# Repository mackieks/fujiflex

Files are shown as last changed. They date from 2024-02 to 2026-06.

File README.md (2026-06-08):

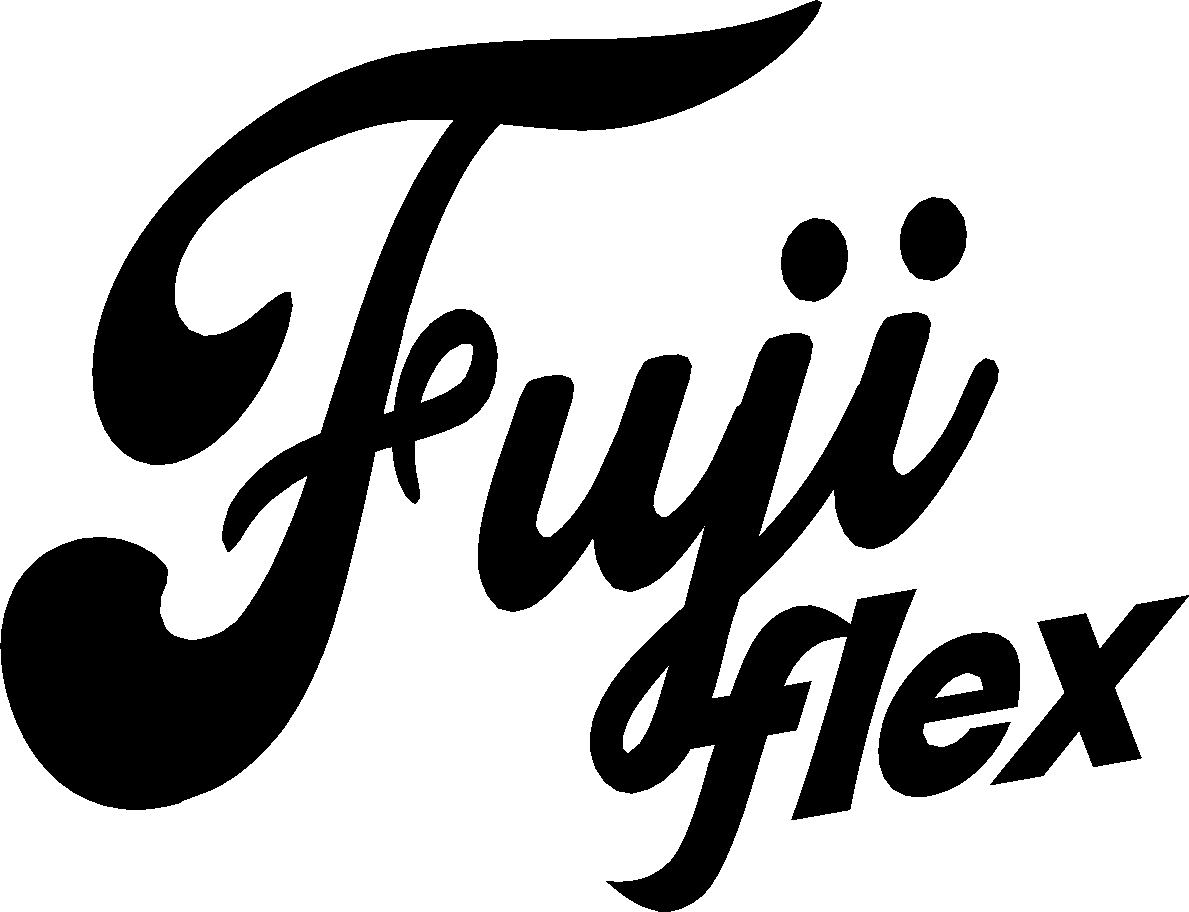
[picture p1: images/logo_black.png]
<picture> <source media="(prefers-color-scheme: dark)" srcset="images/logo.png">  </picture> 

OSHW GCVideo DVI flex for Nintendo Wii. Tested and working! Solderpad Hardware License v2.1

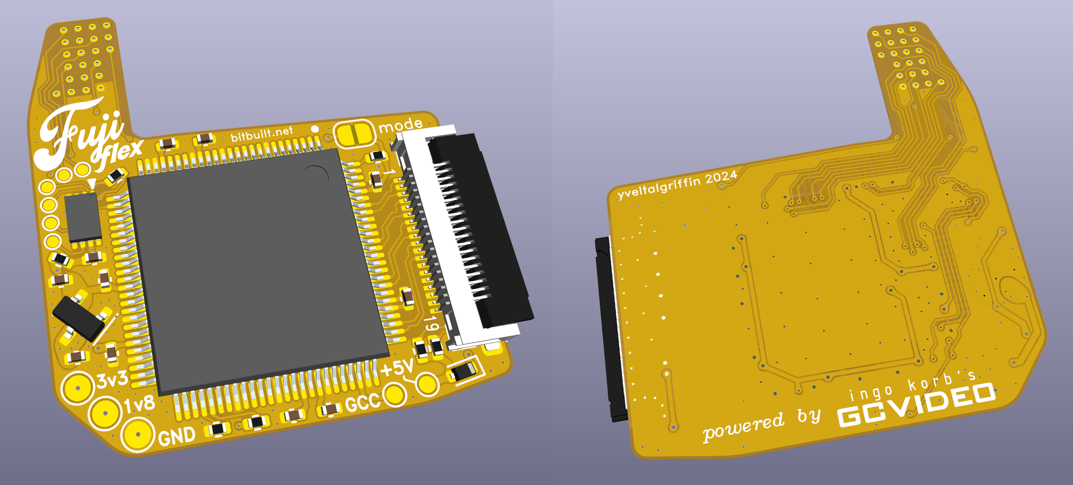
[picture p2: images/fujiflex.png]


Special thanks to [loopj](https://github.com/loopj) for testing the FPC and writing the assembly+install documentation!

## fujiflex features
- [x] Compact 28 x 30mm 2-layer flex PCB (requires KiCAD 8.0 or later)
- [x] ~$10 BOM cost
- [x] Powered from 3.3V and 1.8V (1.2V generated from 1.8V)
- [x] 34mA @ 3.3V + 63mA @ 1.8V = 225mW power consumption
- [x] 19-pin Molex 5052781933 / 5052781970 ZIF for HDMI output
- [x] Wii SDA and SCL testpoints
- [x] MODE solder jumper
- [x] Powered by [Ingo Korb's](https://github.com/ikorb) [GCVideo DVI](https://github.com/ikorb/gcvideo/)

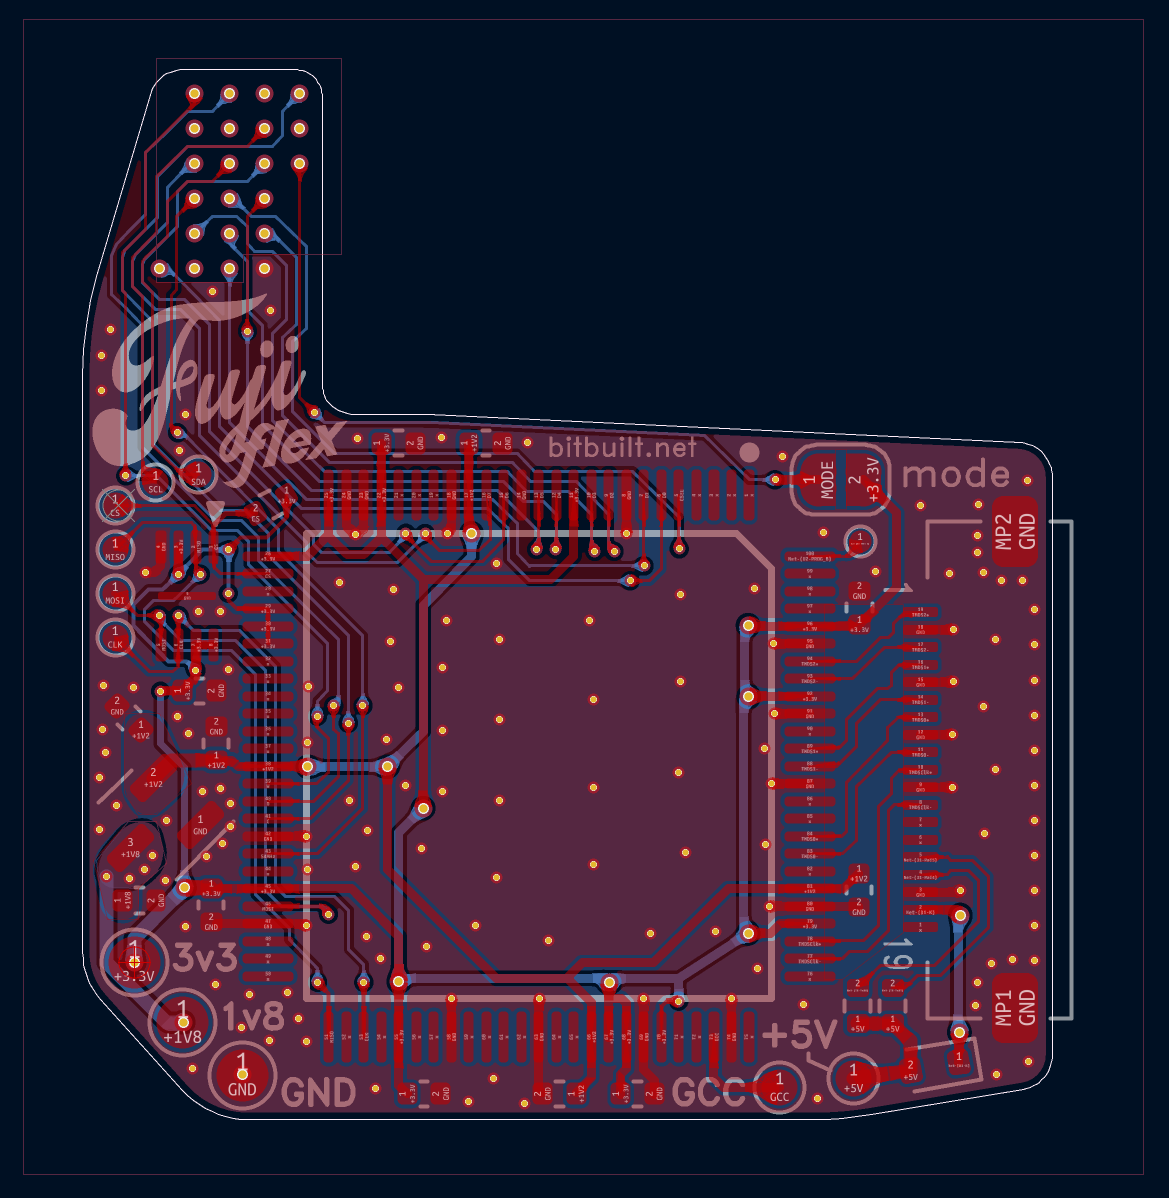
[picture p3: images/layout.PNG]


## Ordering & Assembly
- Download the latest gerber ZIP from [the gerbers folder](https://github.com/mackieks/fujiflex/tree/main/Gerbers).
- Order design as a 2-layer flexible PCB from JLCPCB, PCBWay, GoldPhoenix, or OSHPark.
- **MANDATORY:** FPC must use at least **0.5oz/in² copper** 
- If ordering from JLCPCB, you **must** select **0.12mm thickness** to get 0.5oz!
- A steel solderpaste stencil with etching or electropolishing is **highly** recommended for assembly. JLCPCB is a good source.

I maintain [a Mouser project](https://www.mouser.com/ProjectManager/ProjectDetail.aspx?AccessID=5589d512f3) with most of the BOM. You still need to source the FPGA from elsewhere. I suggest either [LCSC](https://www.lcsc.com/product-detail/Programmable-Logic-Device-CPLDs-FPGAs_XILINX-XC3S200A-4VQG100C_C1521645.html), [AliExpress](https://www.aliexpress.us/item/3256805017536134.html), or [Taobao](https://item.taobao.com/item.htm?abbucket=5&id=749261010737&ns=1&spm=a21n57.1.0.0.2b93523ch7BSfI).

The total BOM cost for fujiflex is around 10USD. **If you're paying more than $5 per FPGA, you are being ripped off!**

Use the provided [ibom.html](https://github.com/mackieks/fujiflex/blob/main/ibom.html) to guide part placement.

**Note:** If you intend to program the SPI flash in-system, do not place R6. You will need to place it after programming is complete.

## Flashing GCVideo

Once assembled, you'll need to flash the GCVideo bitstream. The cheap 'n' easy approach is to program *in-system* using a SPI flash programmer (EZP20xx, CH341A-based, RPi Pico) soldered to the testpads on fujiflex.

- Remove R6 to avoid powering the FPGA during programming
- Wire the CS, MISO, MOSI, CLK, and GND pads to the corresponding pins on your SPI flash programmer
- Wire the rightmost pad of R6 to 3.3V on your SPI flash programmer
- Download the *shuriken-v3-wii* bitstream from [GCVideo's latest release](https://github.com/ikorb/gcvideo/releases/latest)
- Write the bitstream (eg. `gcvideo-dvi-shuriken-v3-wii-3.1-spirom-complete.bin`) to the SPI flash (see below)
- Populate R6 (0402 0Ω)

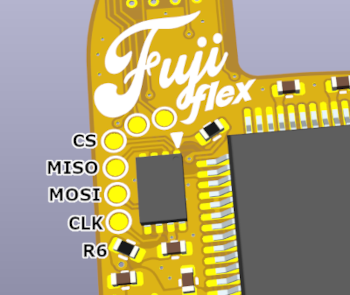
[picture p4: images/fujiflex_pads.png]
fujiflex pads


### EZP20xx programmers

If you are using an EZP20xx programmer, you can flash the bitstream using the [Windows software](https://www.chipsetpro.com/en/content/7-download-software) for these devices.

### Other programmers (using `flashrom`)

For other programmers, [flashrom](https://flashrom.org) is an open source command line tool for programming flash chips which supports [tons of devices](https://wiki.flashrom.org/Supported_programmers), including the inexpensive CH341A-based boards.

First expand the GCVideo bitstream to match the size of the SPI flash chip:

```sh
fallocate -l 512k gcvideo-dvi-shuriken-v3-wii-3.1-spirom-complete.bin
````

Then flash the bitstream, for example with a CH341A programmer:

```sh
flashrom --programmer ch341a_spi -w gcvideo-dvi-shuriken-v3-wii-3.1-spirom-complete.bin
```

### Socket adapters

You can also use a DFN8 2x3mm socket to program the SPI flash before soldering it to the board. [Type 1](https://www.aliexpress.us/item/3256802266989931.html), [Type 2](https://www.aliexpress.us/item/3256801780444965.html)

## Installation

fujiflex is soldered directly to the [digital A/V vias](https://github.com/ikorb/gcvideo/blob/main/HDL/gcvideo_dvi/README-Wii.md#digital-audio-and-video) on a 4-layer Wii motherboard.

- Align and solder fujiflex to the GPU vias
- Wire the 1.8V, 3.3V, 5V, and GND pads
- To use a Gamecube controller for navigating the GCVideo OSD, you'll also need to [wire the GCC pad](https://github.com/ikorb/gcvideo/blob/main/HDL/gcvideo_dvi/README-Wii.md#controller) (or [via](https://bitbuilt.net/forums/index.php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,GameCube%20controllers)).

Installation Photo:

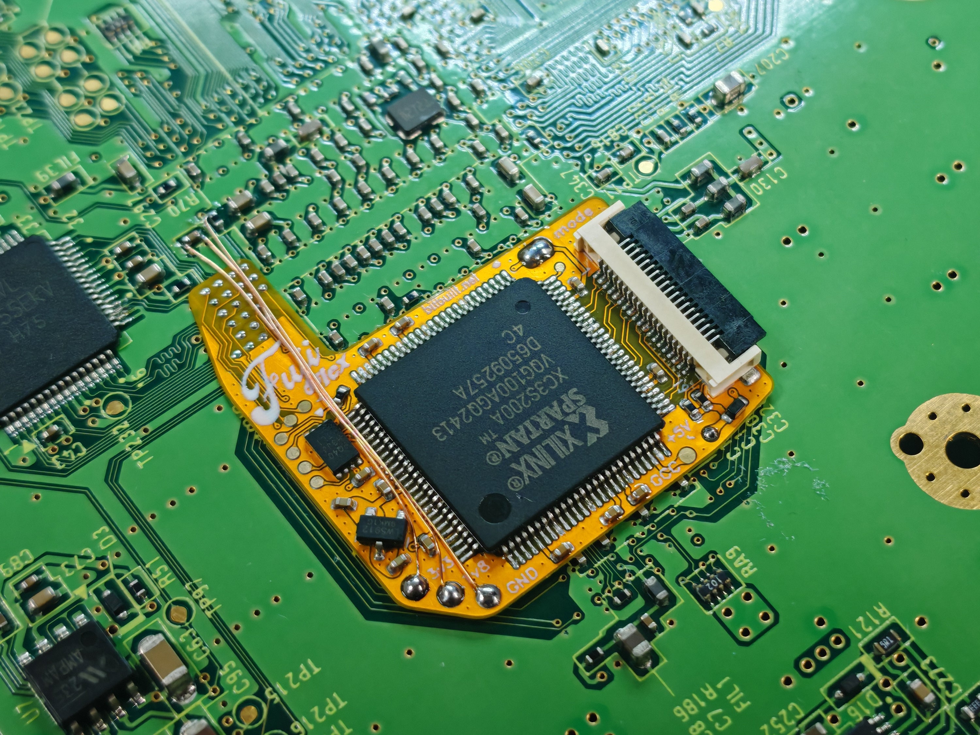
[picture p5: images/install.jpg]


## License

Solderpad Hardware License v2.1

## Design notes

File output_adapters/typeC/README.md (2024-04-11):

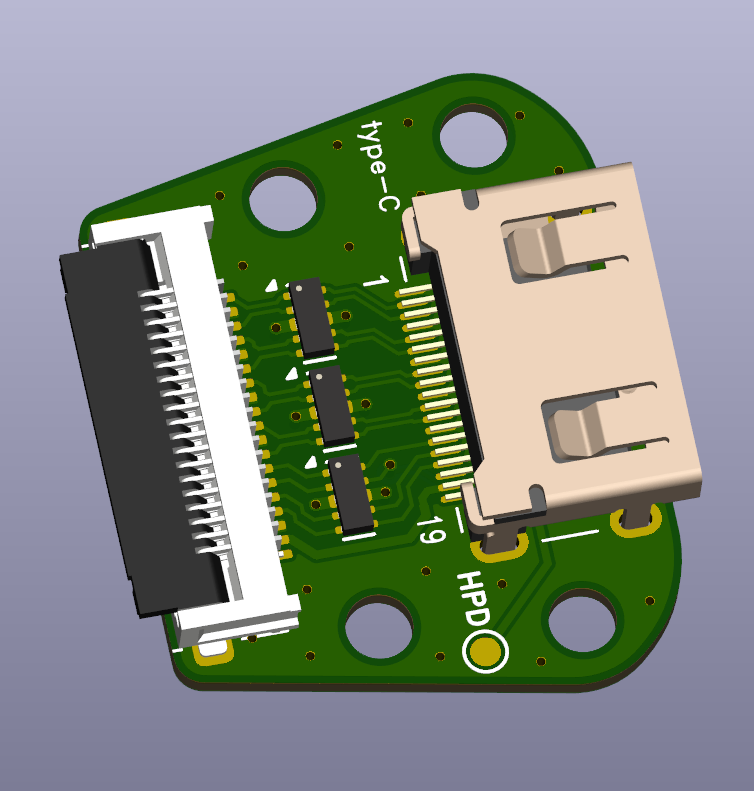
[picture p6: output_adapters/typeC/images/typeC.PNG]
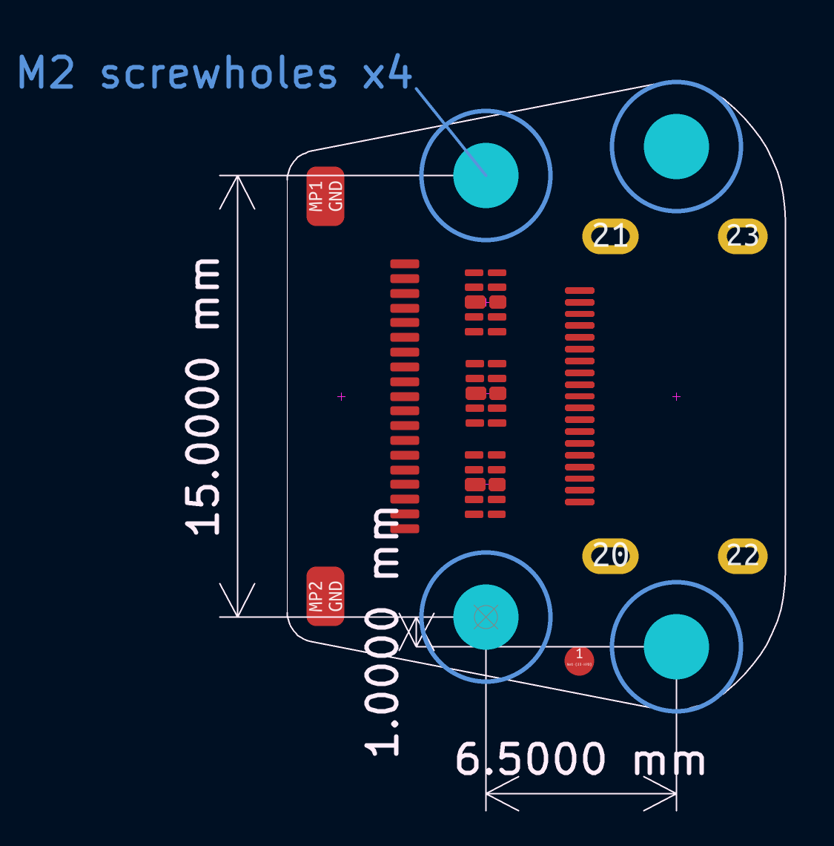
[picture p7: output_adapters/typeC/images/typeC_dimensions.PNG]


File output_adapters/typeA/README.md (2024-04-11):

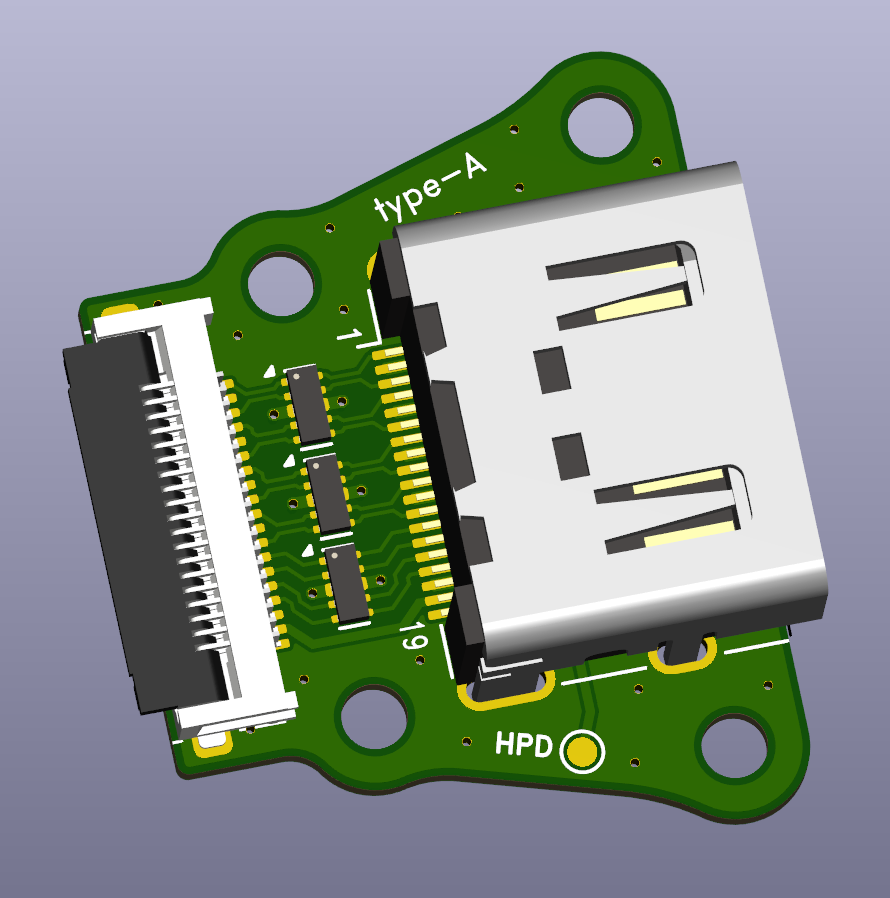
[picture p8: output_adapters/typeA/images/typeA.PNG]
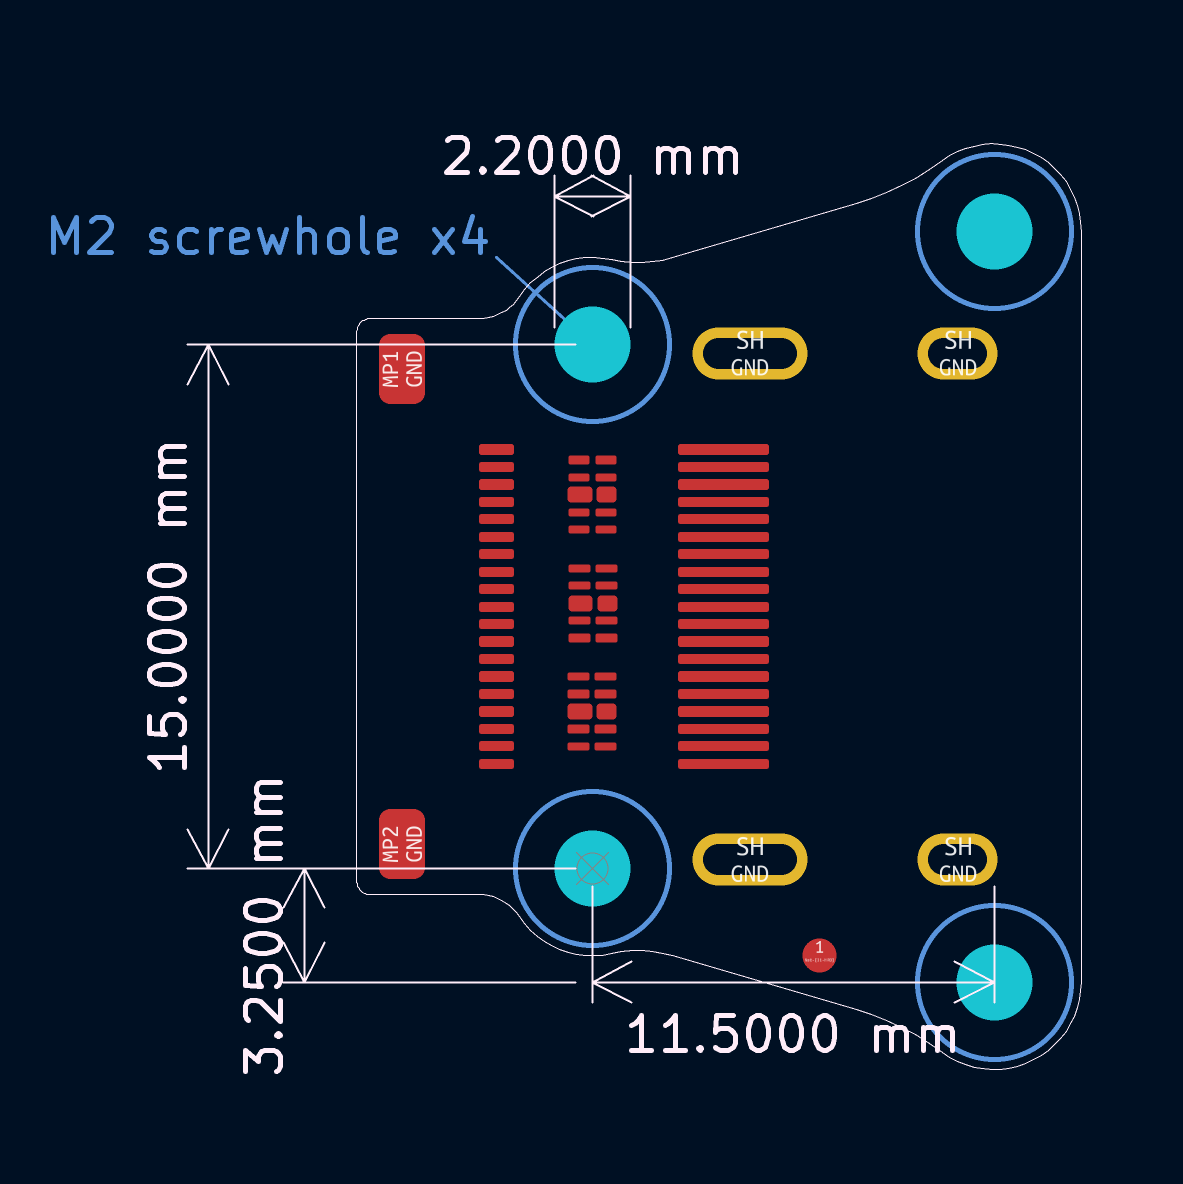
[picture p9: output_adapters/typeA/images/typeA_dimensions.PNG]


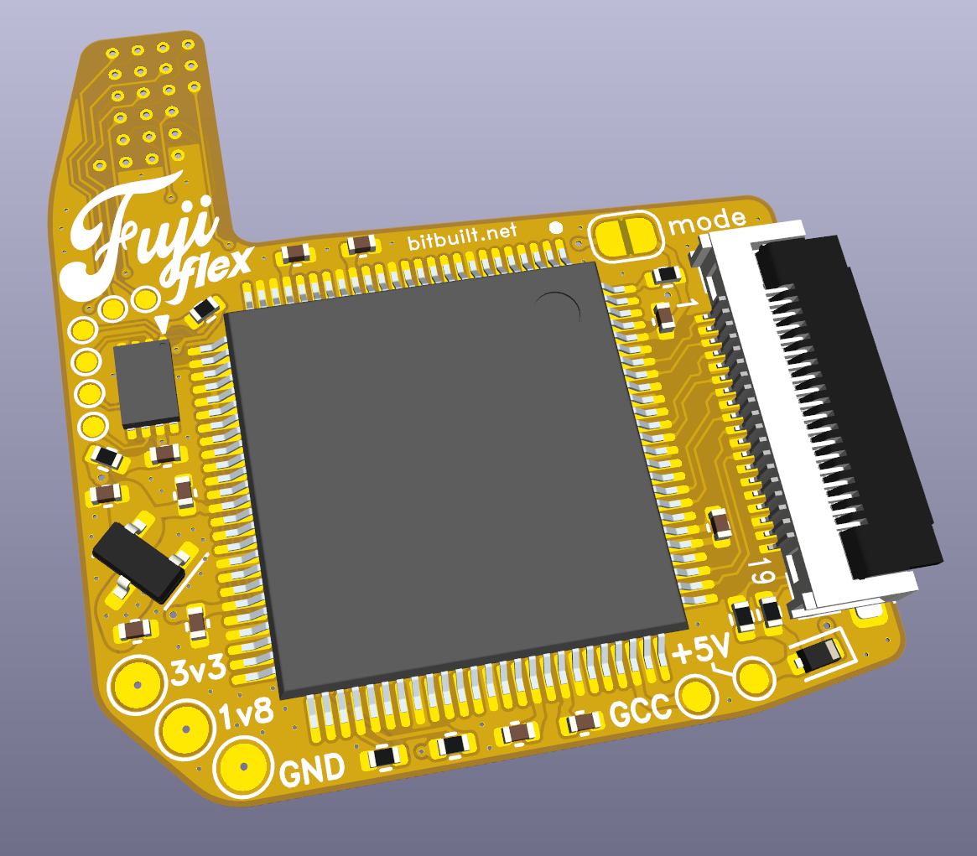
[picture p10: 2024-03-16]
images/fujiflex_top.png

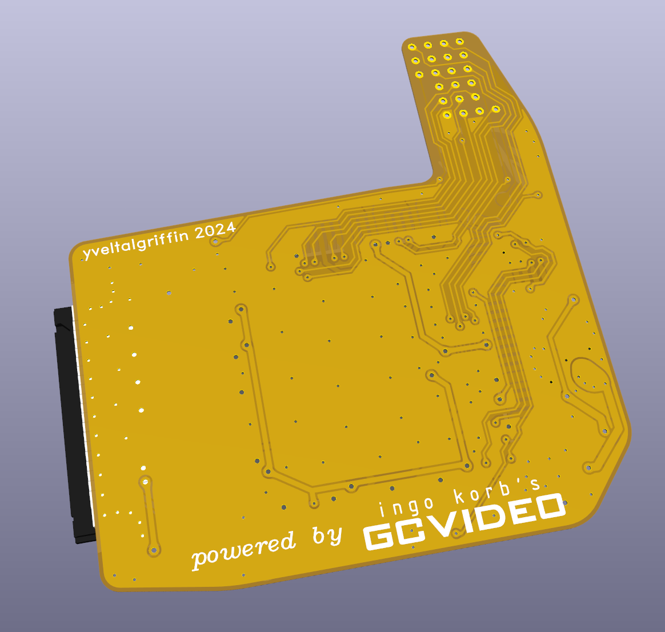
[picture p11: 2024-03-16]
images/fujiflex_bot.png

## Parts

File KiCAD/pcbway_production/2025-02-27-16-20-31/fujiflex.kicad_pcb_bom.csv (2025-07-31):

Designator | Quantity | Value | Footprint | Package | MPN | DNP | Mount_Type | Description | Height | Mouser Part Number | Mouser Price/Stock | Manufacturer_Name
C1, C2 | 2 | 1uF | C_0402_1005Metric |  |  |  | smt | Unpolarized capacitor, small symbol
C10, C11, C12, C3, C4, C5, C6, C7, C8, C9 | 10 | 0.1uF | C_0402_1005Metric |  |  |  | smt | Unpolarized capacitor, small symbol
D1 | 1 | BAT54XV2T1G | D_SOD-523 |  |  |  | smt
J1 | 1 | 505278-1933 | 5052781933 |  | 505278-1933 |  | smt | FFC & FPC Connectors 0.5 FFC ZIF BTM CONT 19Ckt R/A FRONT FLIP | 2.15 | 538-505278-1933 | https://www.mouser.co.uk/ProductDetail/Molex/505278-1933?qs=c8NFF48pVsDT1Rm30ZuzyA%3D%3D | Molex
JP1 | 1 | SolderJumper_2_Open | SolderJumper-2_P1.3mm_Open_RoundedPad1.0x1.5mm |  |  |  | tht | Solder Jumper, 2-pole, open
R1, R2, R3 | 3 | 10k | R_0402_1005Metric |  |  |  | smt | Resistor, small symbol
TP1, TP10, TP11, TP12, TP6, TP7, TP9 | 7 | TestPoint | TestPoint_Pad_D0.75mm |  |  |  | tht | test point
TP2, TP3, TP4 | 3 | TestPoint | TestPoint_Pad_D1.5mm |  |  |  | tht | test point
TP5, TP8 | 2 | TestPoint | TestPoint_Pad_D1.0mm |  |  |  | tht | test point
U1 | 1 | TPS7A0512PDBZR | SOT-23 |  |  |  | smt
U2 | 1 | XC3S200A-4VQG100C | QFP50P1600X1600X120-100N |  | XC3S200A-4VQG100C |  | smt | Spartan-3A FPGA 200k gates VQFP100 XC3S200A-4VQG100C, FPGA Spartan-3A 4032 Cells, 200000 Gates, 28672bit, 4032 Blocks, 1.14 1.26 V 100-Pin VTQFP | 1.2 | 217-C3S200A-4VQG100C | https://www.mouser.co.uk/ProductDetail/Xilinx/XC3S200A-4VQG100C?qs=rrS6PyfT74eGc8DZ2cmrnA%3D%3D | XILINX
U3 | 1 | AT25SF041B-MAHD-T | SON50P300X200X60-9N-D |  | AT25SF041B-MAHD-T |  | smt | The AT25SF041B is a member of our standard class code and data storage solutions designed for 3V systems in which program code is shadowed from Flash memory into embedded or external RAM for execution.The architecture includes erase block sizes that are optimized to meet the needs of today's code and data storage applications and three security register pages for unique device serialization, system-level Electronic Serial Number (ESN) storage, locked key storage, etc. Universally compatible pinout and comma | 0.6 | 988-AT25SF041BMAHDT | https://www.mouser.co.uk/ProductDetail/Renesas-Dialog/AT25SF041B-MAHD-T?qs=IS%252B4QmGtzzqoh2maLIY0qQ%3D%3D | Renesas Electronics

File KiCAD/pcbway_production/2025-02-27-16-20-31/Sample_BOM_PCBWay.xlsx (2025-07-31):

 |  |  | fujiflex_2025-02-27 100PCS BOM
Item # | Designator | Qty | Manufacturer | Mfg Part # | Description / Value | Package/Footprint | Type | Your Instructions / Notes
1 | C1, C2 | 2 |  |  | 1uF 25V X5R | C0402 | smt
2 | C10, C11, C12, C3, C4, C5, C6, C7, C8, C9 | 10 |  |  | 0.1uF 16V X7R | C0402 | smt
3 | D1 | 1 | SLKORMICRO Elec | 1N5819WT | Schottky Diode | SOD-523 | smt
4 | J1 | 1 | Molex | 505278-1933 |  |  | smt | [Supplied by customer客供]
5 | R1, R2, R3 | 3 |  |  | 10kΩ 1% | R0402 | smt
6 | U1 | 1 | Lewa Micro | LW5912N23D | 1.2V output LDO regulator | SOT-23-3L | smt
7 | U2 | 1 | Xilinx / AMD | XC3S200A-4VQG100C | Spartan-3A FPGA | TQFP-100 | smt | [Supplied by customer客供]
8 | U3 | 1 | PUYA | P25Q40H-UXH-IR | 4Mbit SPI flash | USON-8-EP(2x3) | smt | [Supplied by customer客供]
9
10
11
12
13
14
15

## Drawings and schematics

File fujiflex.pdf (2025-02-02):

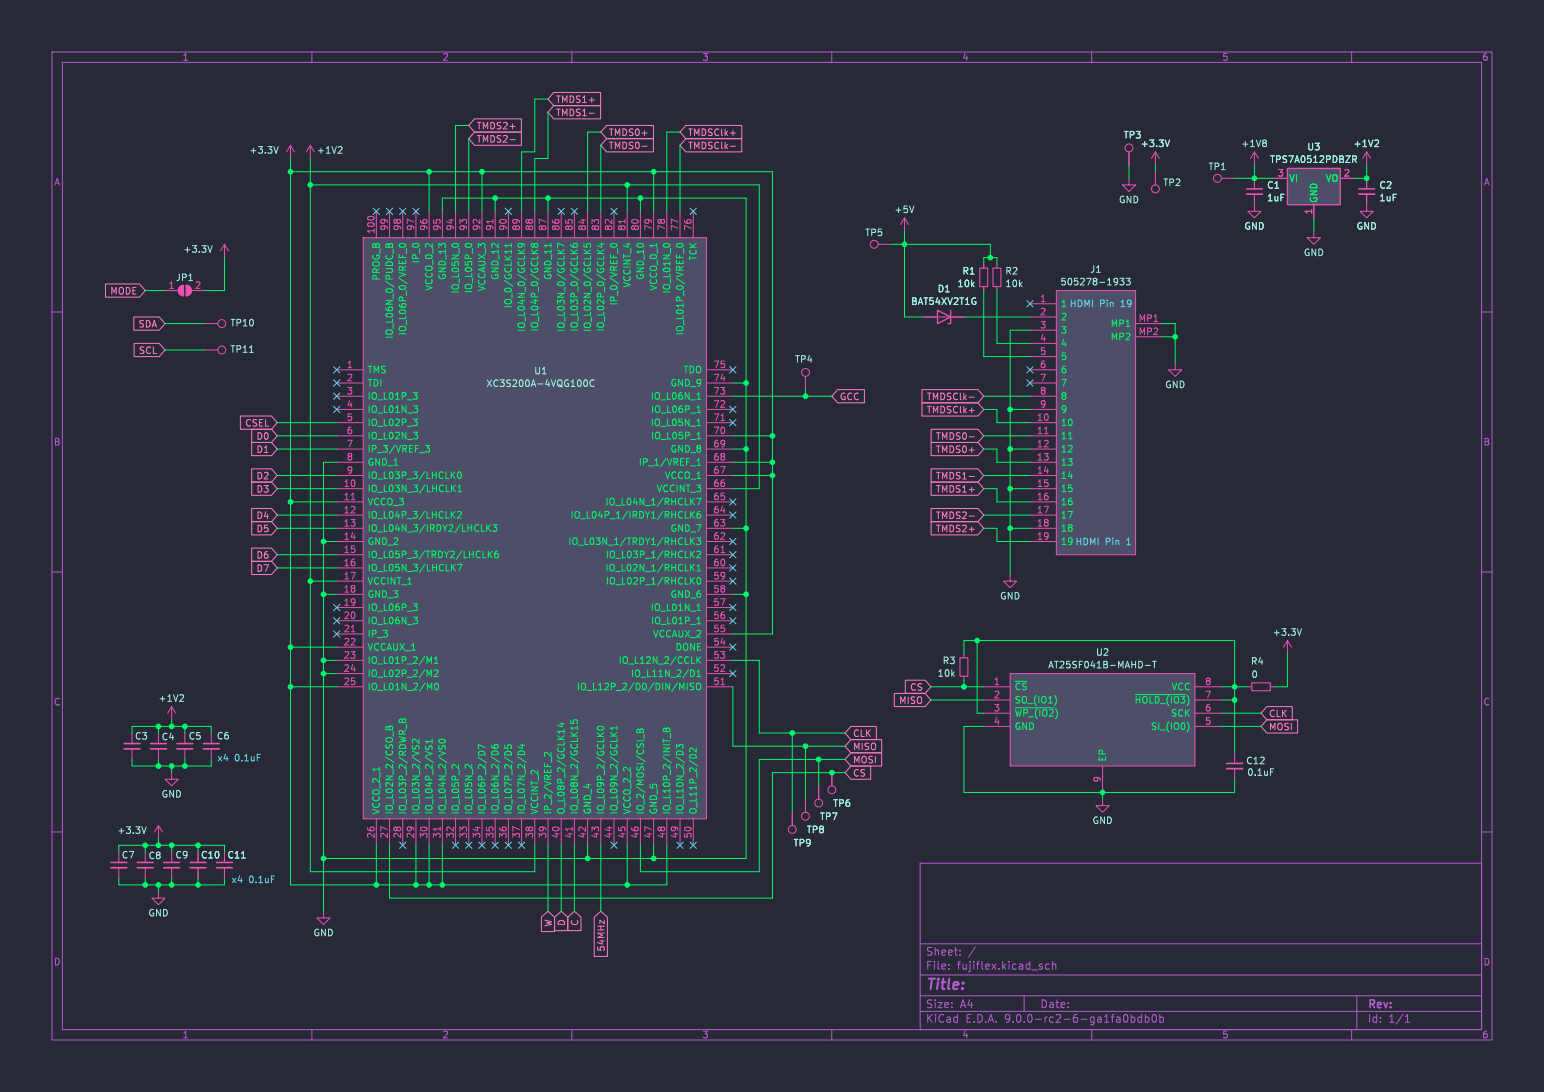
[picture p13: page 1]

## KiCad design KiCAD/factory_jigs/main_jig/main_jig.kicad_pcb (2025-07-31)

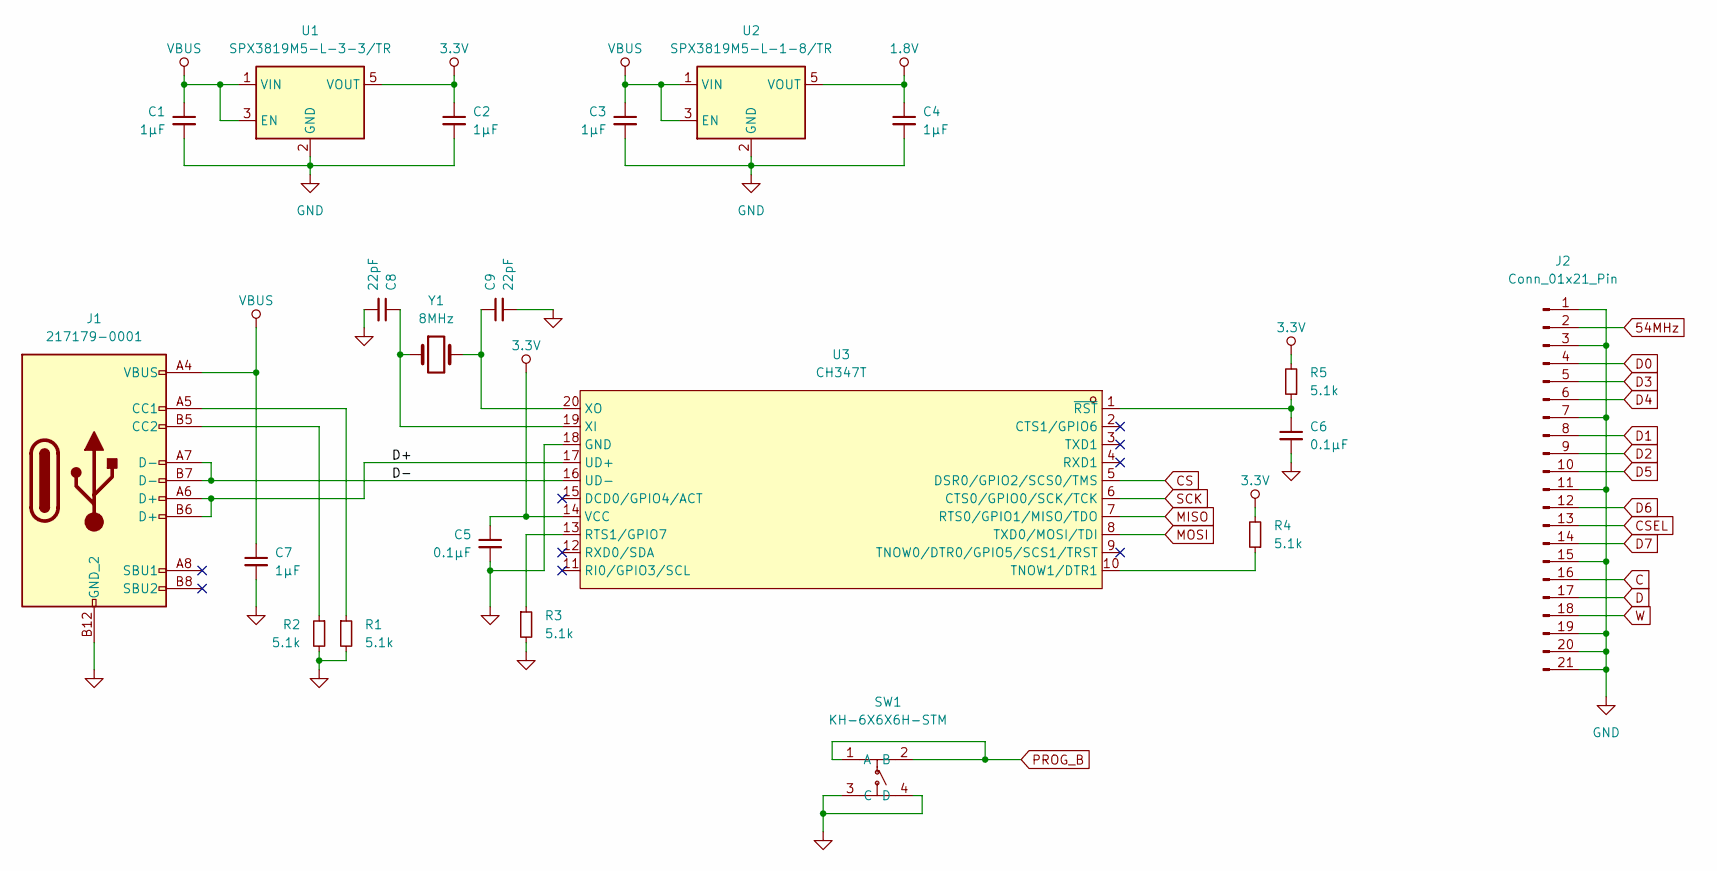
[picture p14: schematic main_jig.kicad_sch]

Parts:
C1, C2, C3, C4, C7: 1µF; C_0402_1005Metric
C5, C6: 0.1µF; C_0402_1005Metric
C8, C9: 22pF; C_0402_1005Metric
J1: 217179-0001; USB-C_SMD-TYPE-C-31-M-12
J2: Conn_01x21_Pin; FPC-SMD_19P-P0.50_AFD01-S19FCA-00
R1, R2, R3, R4, R5: 5.1k; R_0402_1005Metric
SW1: KH-6X6X6H-STM; SW-SMD_4P-L6.0-W6.0-P4.50-LS9.0-3; LCSC Part C2837532
U1: SPX3819M5-L-3-3/TR; SOT-23-5
U2: SPX3819M5-L-1-8/TR; SOT-23-5
U3: CH347T; TSSOP-20_L6.5-W4.4-P0.65-LS6.4-BL; LCSC Part C5122332
Y1: 8MHz; Crystal_SMD_5032-2Pin_5.0x3.2mm

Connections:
1.8V: C4.1, U2.5 (VOUT)
3.3V: C2.1, C5.1, R4.2, R5.2, U1.5 (VOUT), U3.14 (VCC)
54MHz: J2.2
/D+: J1.A6 (D+), J1.B6 (D+), U3.17 (UD+)
/D-: J1.A7 (D-), J1.B7 (D-), U3.16 (UD-)
C: J2.16
CS: U3.5 (DSR0/GPIO2/SCS0/TMS)
CSEL: J2.13
D: J2.17
D0: J2.4
D1: J2.8
D2: J2.9
D3: J2.5
D4: J2.6
D5: J2.10
D6: J2.12
D7: J2.14
GND: C1.2, C2.2, C3.2, C4.2, C5.2, C6.2, C7.2, C8.2, C9.2, J1.0 (GND_2), J1.1 (GND_2), J1.2 (GND_2), J1.3 (GND_2), J1.A1 (GND_2), J1.A12 (GND_2), J1.B1 (GND_2), J1.B12 (GND_2), J2.1, J2.3, J2.7, J2.11, J2.15, J2.19, J2.20, J2.21, R1.2, R2.2, R3.2, SW1.3 (C), SW1.4 (D), U1.2 (GND), U2.2 (GND), U3.18 (GND)
MISO: U3.7 (RTS0/GPIO1/MISO/TDO)
MOSI: U3.8 (TXD0/MOSI/TDI)
unnamed: J1.A5 (CC1), R1.1
unnamed: J1.B5 (CC2), R2.1
unnamed: R3.1, U3.13 (RTS1/GPIO7)
unnamed: R4.1, U3.10 (TNOW1/DTR1)
unnamed: C8.1, U3.19 (XI), Y1.1
unnamed: C9.1, U3.20 (XO), Y1.2
unnamed: C6.1, R5.1, U3.1 (~RST)
PROG_B: SW1.1 (A), SW1.2 (B)
SCK: U3.6 (CTS0/GPIO0/SCK/TCK)
VBUS: C1.1, C3.1, C7.1, J1.A4 (VBUS), J1.A9 (VBUS), J1.B4 (VBUS), J1.B9 (VBUS), U1.1 (VIN), U1.3 (EN), U2.1 (VIN), U2.3 (EN)
W: J2.18

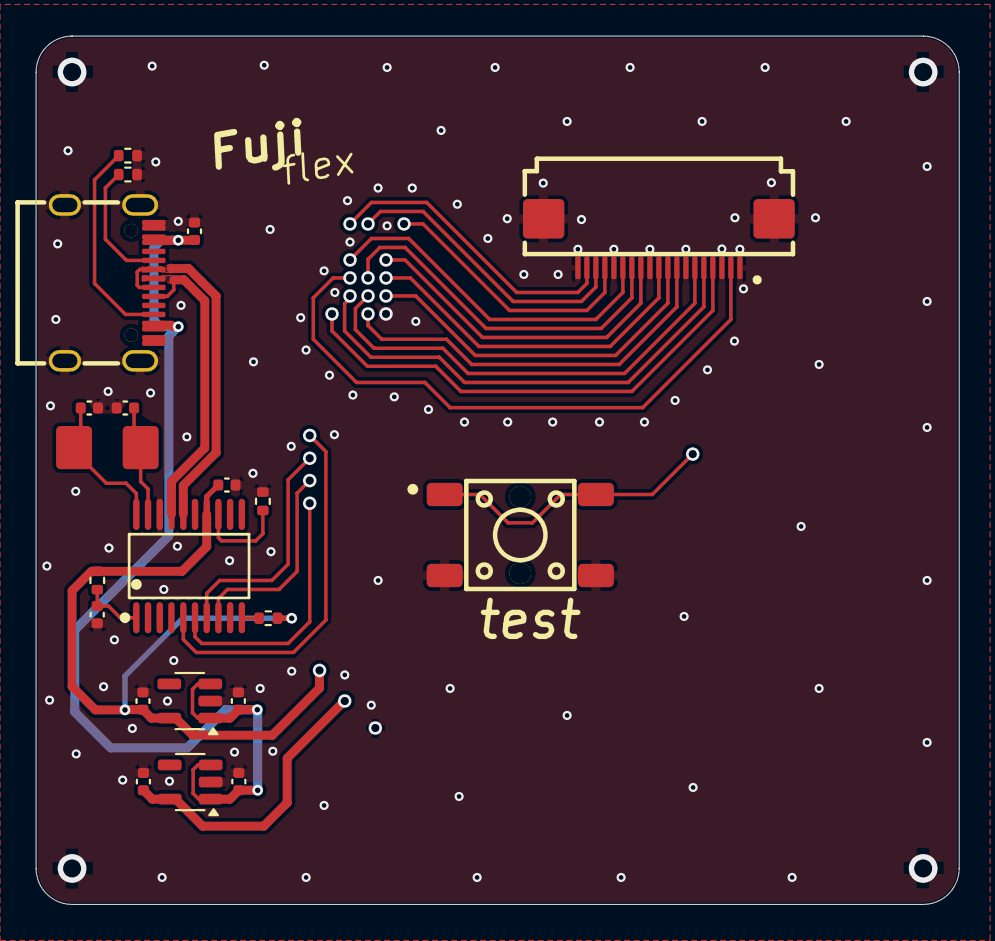
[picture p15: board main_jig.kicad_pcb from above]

Board: 2 copper layers, 51.3 x 48.2 mm, 21 parts (0 on the bottom side), 14 nets.

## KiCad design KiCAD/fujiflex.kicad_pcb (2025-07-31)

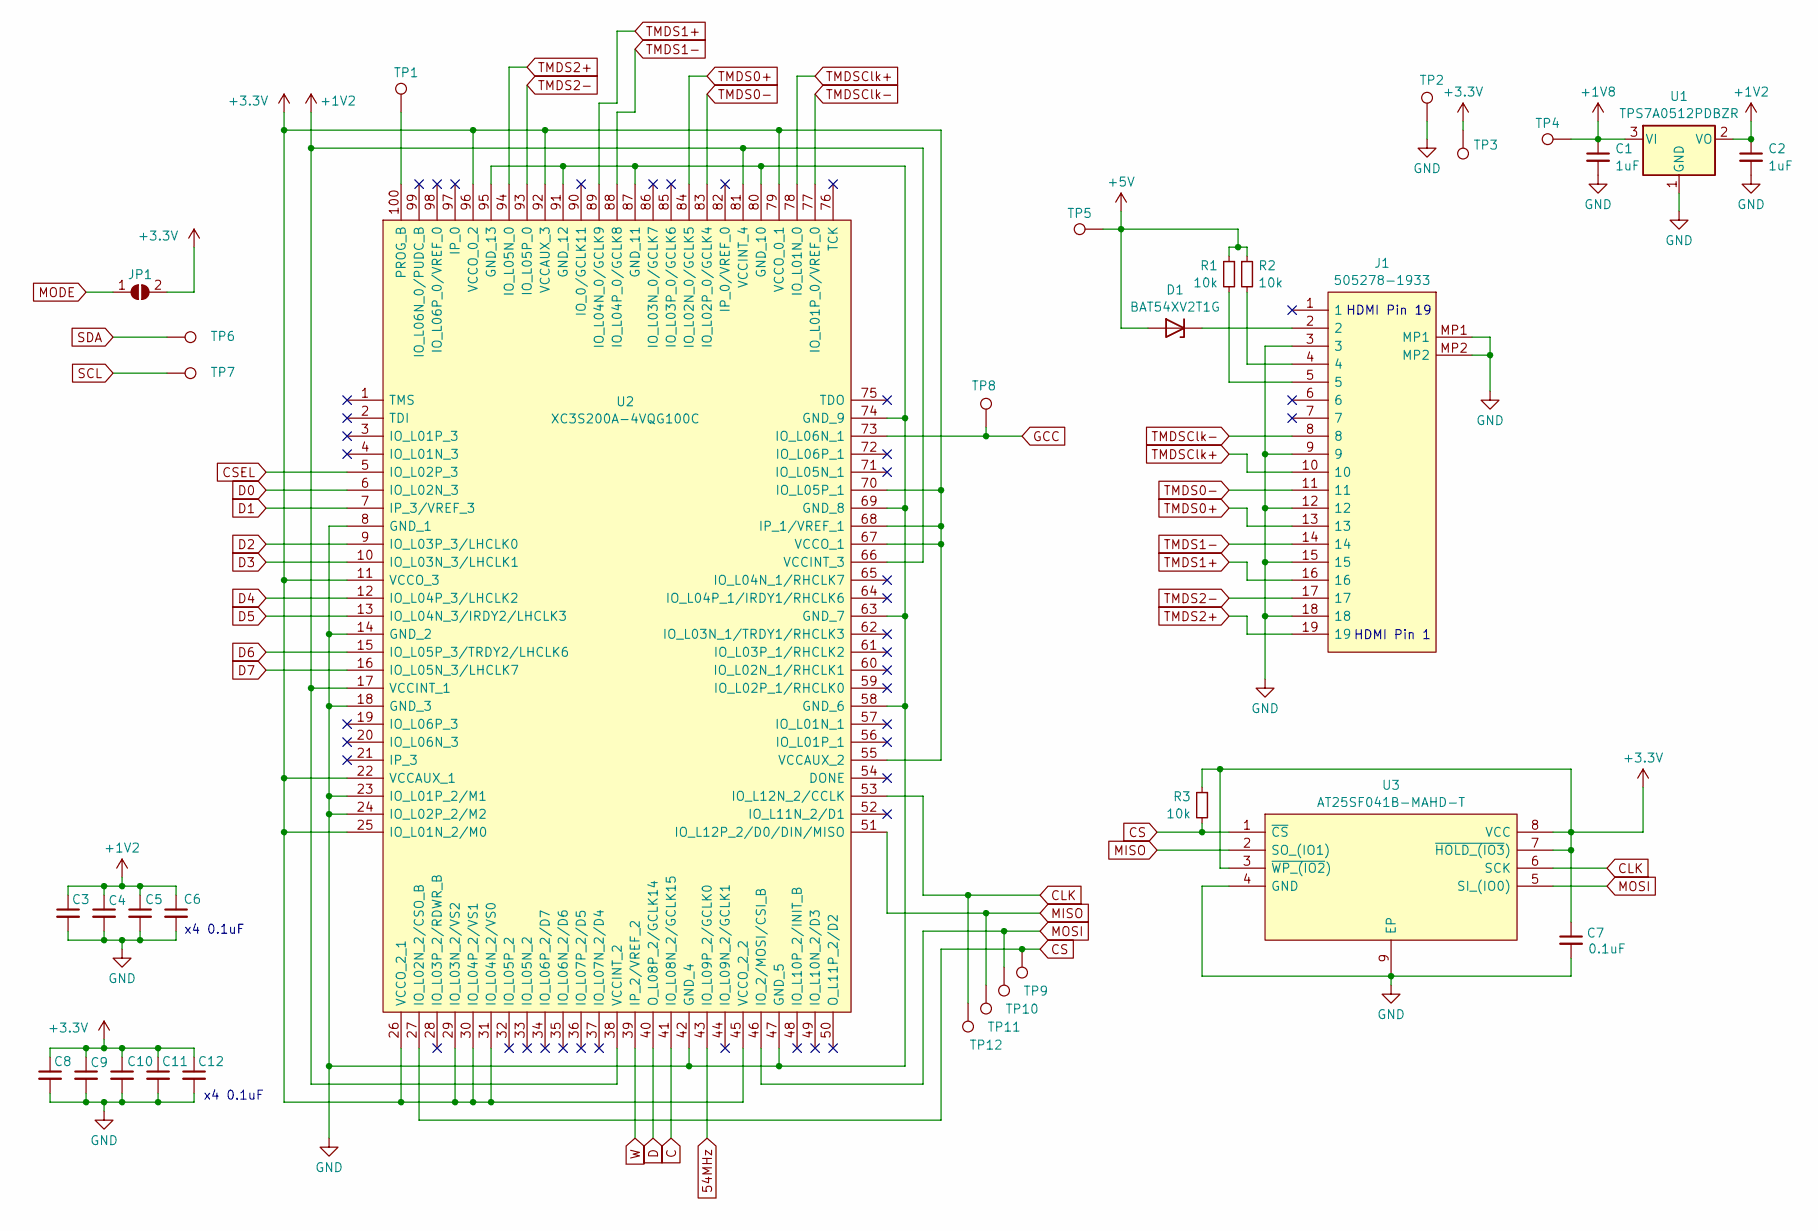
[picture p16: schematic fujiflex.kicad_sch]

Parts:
C1, C2: 1uF; C_0402_1005Metric
C3, C4, C5, C6, C7, C8, C9, C10, C11, C12: 0.1uF; C_0402_1005Metric
D1: BAT54XV2T1G; D_SOD-523
J1: 505278-1933; 5052781933; Mouser Part Number 538-505278-1933
JP1: SolderJumper_2_Open; SolderJumper-2_P1.3mm_Open_RoundedPad1.0x1.5mm
R1, R2, R3: 10k; R_0402_1005Metric
TP1, TP6, TP7, TP9, TP10, TP11, TP12: TestPoint; TestPoint_Pad_D0.75mm
TP2, TP3, TP4: TestPoint; TestPoint_Pad_D1.5mm
TP5, TP8: TestPoint; TestPoint_Pad_D1.0mm
U1: TPS7A0512PDBZR; SOT-23
U2: XC3S200A-4VQG100C; QFP50P1600X1600X120-100N; Mouser Part Number 217-C3S200A-4VQG100C
U3: AT25SF041B-MAHD-T; SON50P300X200X60-9N-D; Mouser Part Number 988-AT25SF041BMAHDT

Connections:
54MHz: U2.43 (IO_L09P_2/GCLK0)
+1V2: C2.1, C3.1, C4.1, C5.1, C6.1, U1.2 (VO), U2.17 (VCCINT_1), U2.38 (VCCINT_2), U2.66 (VCCINT_3), U2.81 (VCCINT_4)
+1V8: C1.1, TP4.1, U1.3 (VI)
+3.3V: C7.1, C8.1, C9.1, C10.1, C11.1, C12.1, JP1.2 (B), R3.1, TP3.1, U2.11 (VCCO_3), U2.22 (VCCAUX_1), U2.25 (IO_L01N_2/M0), U2.26 (VCCO_2_1), U2.29 (IO_L03N_2/VS2), U2.30 (IO_L04P_2/VS1), U2.31 (IO_L04N_2/VS0), U2.45 (VCCO_2_2), U2.55 (VCCAUX_2), U2.67 (VCCO_1), U2.68 (IP_1/VREF_1), U2.70 (IO_L05P_1), U2.79 (VCCO_0_1), U2.92 (VCCAUX_3), U2.96 (VCCO_0_2), U3.3 (~WP_(IO2)), U3.7 (~HOLD_(IO3)), U3.8 (VCC)
+5V: D1.2 (A), R1.1, R2.1, TP5.1
C: U2.41 (IO_L08N_2/GCLK15)
CLK: TP12.1, U2.53 (IO_L12N_2/CCLK), U3.6 (SCK)
CS: R3.2, TP9.1, U2.27 (IO_L02N_2/CSO_B), U3.1 (~CS)
CSEL: U2.5 (IO_L02P_3)
D: U2.40 (O_L08P_2/GCLK14)
D0: U2.6 (IO_L02N_3)
D1: U2.7 (IP_3/VREF_3)
D2: U2.9 (IO_L03P_3/LHCLK0)
D3: U2.10 (IO_L03N_3/LHCLK1)
D4: U2.12 (IO_L04P_3/LHCLK2)
D5: U2.13 (IO_L04N_3/IRDY2/LHCLK3)
D6: U2.15 (IO_L05P_3/TRDY2/LHCLK6)
D7: U2.16 (IO_L05N_3/LHCLK7)
GCC: TP8.1, U2.73 (IO_L06N_1)
GND: C1.2, C2.2, C3.2, C4.2, C5.2, C6.2, C7.2, C8.2, C9.2, C10.2, C11.2, C12.2, J1.3, J1.9, J1.12, J1.15, J1.18, J1.MP1, J1.MP2, TP2.1, U1.1 (GND), U2.8 (GND_1), U2.14 (GND_2), U2.18 (GND_3), U2.23 (IO_L01P_2/M1), U2.24 (IO_L02P_2/M2), U2.42 (GND_4), U2.47 (GND_5), U2.58 (GND_6), U2.63 (GND_7), U2.69 (GND_8), U2.74 (GND_9), U2.80 (GND_10), U2.87 (GND_11), U2.91 (GND_12), U2.95 (GND_13), U3.4 (GND), U3.9 (EP)
MISO: TP11.1, U2.51 (IO_L12P_2/D0/DIN/MISO), U3.2 (SO_(IO1))
MODE: JP1.1 (A)
MOSI: TP10.1, U2.46 (IO_2/MOSI/CSI_B), U3.5 (SI_(IO0))
unnamed: D1.1 (K), J1.2
unnamed: J1.4, R2.2
unnamed: J1.5, R1.2
unnamed: TP1.1, U2.100 (PROG_B)
SCL: TP7.1
SDA: TP6.1
TMDS0+: J1.13, U2.84 (IO_L02N_0/GCLK5)
TMDS0-: J1.11, U2.83 (IO_L02P_0/GCLK4)
TMDS1+: J1.16, U2.89 (IO_L04N_0/GCLK9)
TMDS1-: J1.14, U2.88 (IO_L04P_0/GCLK8)
TMDS2+: J1.19, U2.94 (IO_L05N_0)
TMDS2-: J1.17, U2.93 (IO_L05P_0)
TMDSClk+: J1.10, U2.78 (IO_L01N_0)
TMDSClk-: J1.8, U2.77 (IO_L01P_0/VREF_0)
W: U2.39 (IP_2/VREF_2)

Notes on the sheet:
HDMI Pin 1
x4 0.1uF
HDMI Pin 19

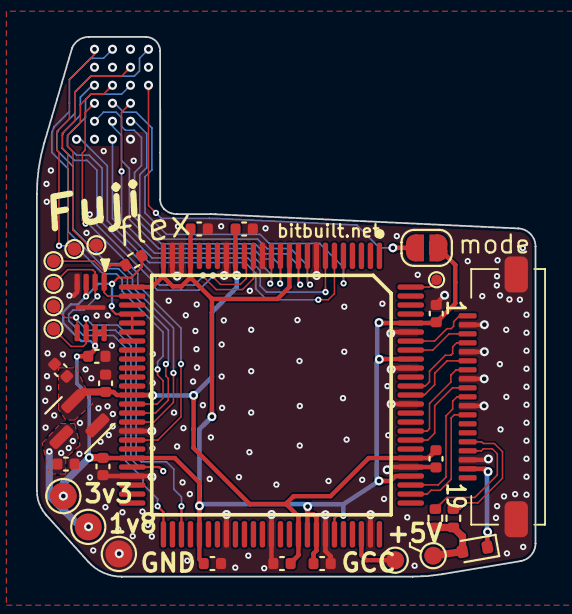
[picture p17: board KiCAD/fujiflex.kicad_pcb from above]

Board: 2 copper layers, 27.7 x 30.0 mm, 33 parts (0 on the bottom side), 22 nets.

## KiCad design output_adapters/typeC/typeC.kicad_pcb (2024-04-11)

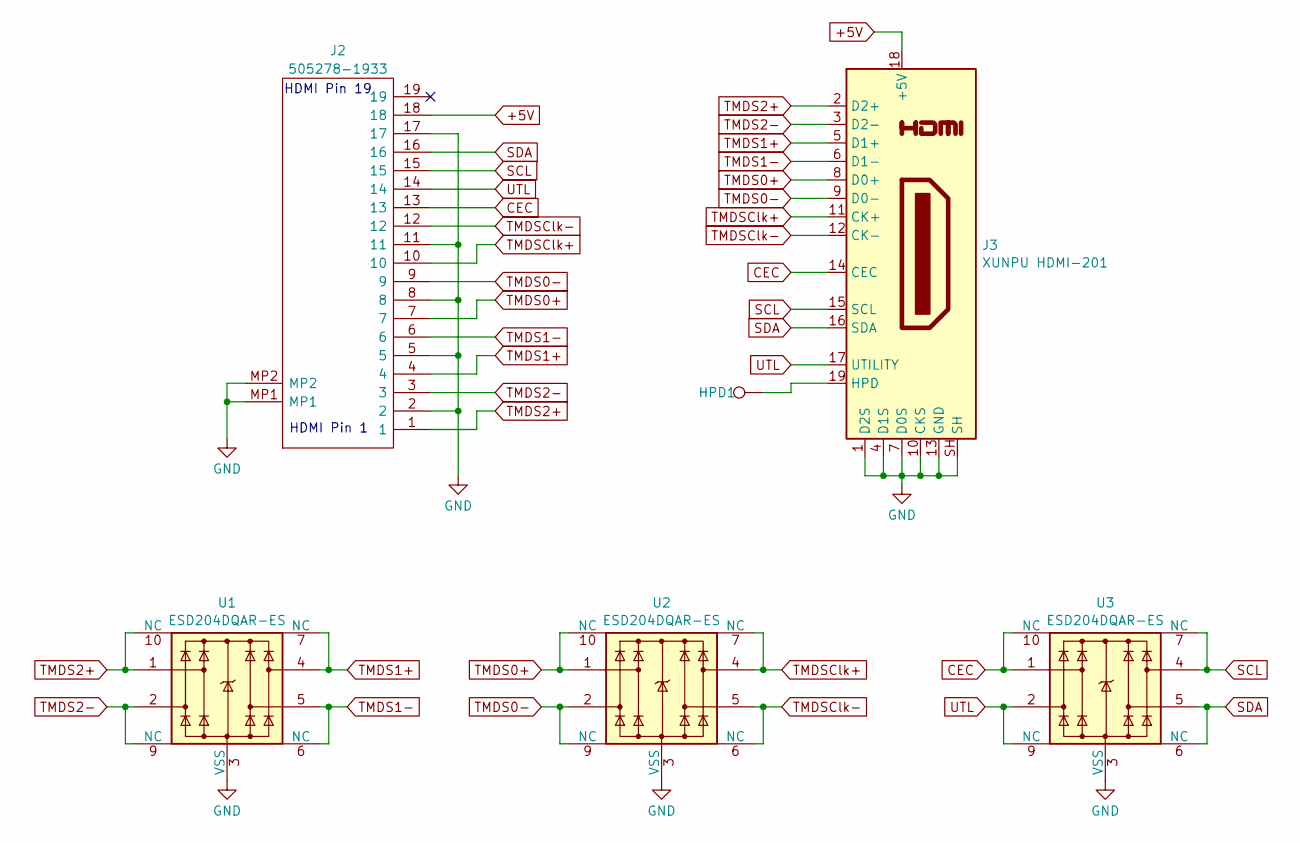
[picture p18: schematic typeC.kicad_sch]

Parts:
HPD1: TestPoint; TestPoint_Pad_D1.0mm
J2: 505278-1933; 5052781933; Mouser Part Number 538-505278-1933
J3: XUNPU HDMI-201; 685119136923
U1, U2, U3: ESD204DQAR-ES; Diodes_UDFN-10_1.0x2.5mm_P0.5mm

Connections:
+5V: J2.18, J3.18 (+5V)
CEC: J2.13, J3.14 (CEC), U3.1, U3.10 (NC)
GND: J2.2, J2.5, J2.8, J2.11, J2.17, J2.MP1, J2.MP2, J3.1 (D2S), J3.4 (D1S), J3.7 (D0S), J3.10 (CKS), J3.13 (GND), J3.SH, U1.3 (VSS), U1.8 (VSS), U2.3 (VSS), U2.8 (VSS), U3.3 (VSS), U3.8 (VSS)
unnamed: HPD1.1, J3.19 (HPD)
SCL: J2.15, J3.15 (SCL), U3.4, U3.7 (NC)
SDA: J2.16, J3.16 (SDA), U3.5, U3.6 (NC)
TMDS0+: J2.7, J3.8 (D0+), U2.1, U2.10 (NC)
TMDS0-: J2.9, J3.9 (D0-), U2.2, U2.9 (NC)
TMDS1+: J2.4, J3.5 (D1+), U1.4, U1.7 (NC)
TMDS1-: J2.6, J3.6 (D1-), U1.5, U1.6 (NC)
TMDS2+: J2.1, J3.2 (D2+), U1.1, U1.10 (NC)
TMDS2-: J2.3, J3.3 (D2-), U1.2, U1.9 (NC)
TMDSClk+: J2.10, J3.11 (CK+), U2.4, U2.7 (NC)
TMDSClk-: J2.12, J3.12 (CK-), U2.5, U2.6 (NC)
UTL: J2.14, J3.17 (UTILITY), U3.2, U3.9 (NC)

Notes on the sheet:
HDMI Pin 19
HDMI Pin 1

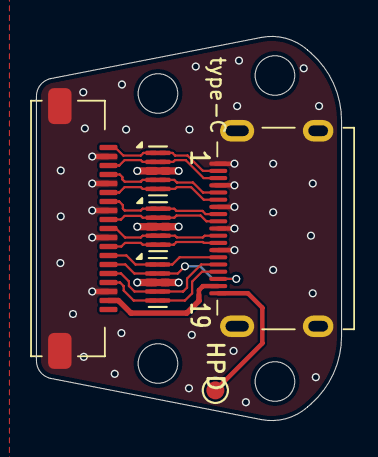
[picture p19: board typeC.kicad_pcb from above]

Board: 2 copper layers, 16.9 x 21.3 mm, 6 parts (0 on the bottom side), 15 nets.

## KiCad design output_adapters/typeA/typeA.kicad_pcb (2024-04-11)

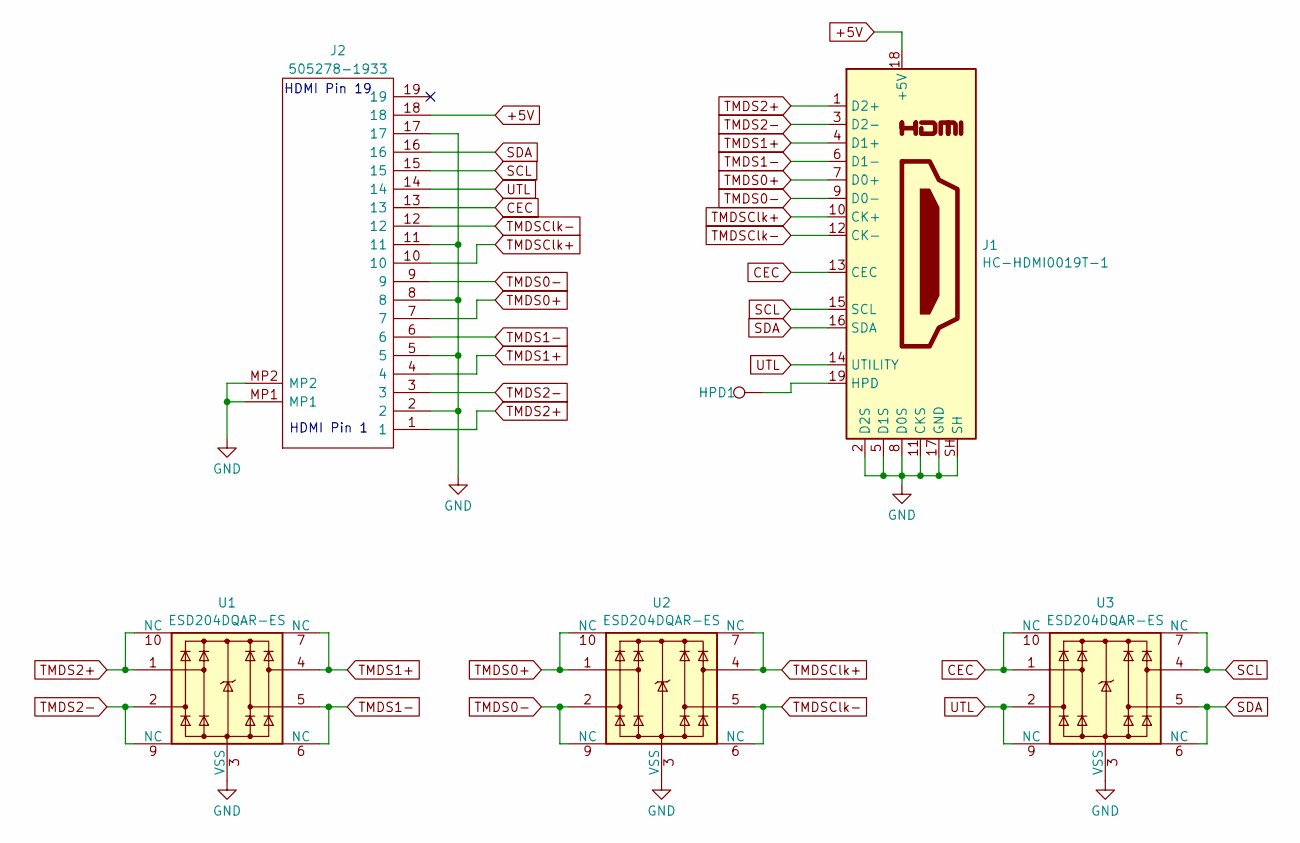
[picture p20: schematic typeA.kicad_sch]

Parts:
HPD1: TestPoint; TestPoint_Pad_D1.0mm
J1: HC-HDMI0019T-1; HDMI_A_Molex_208658-1001_Horizontal
J2: 505278-1933; 5052781933; Mouser Part Number 538-505278-1933
U1, U2, U3: ESD204DQAR-ES; Diodes_UDFN-10_1.0x2.5mm_P0.5mm

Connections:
+5V: J1.18 (+5V), J2.18
CEC: J1.13 (CEC), J2.13, U3.1, U3.10 (NC)
GND: J1.2 (D2S), J1.5 (D1S), J1.8 (D0S), J1.11 (CKS), J1.17 (GND), J1.SH, J2.2, J2.5, J2.8, J2.11, J2.17, J2.MP1, J2.MP2, U1.3 (VSS), U1.8 (VSS), U2.3 (VSS), U2.8 (VSS), U3.3 (VSS), U3.8 (VSS)
unnamed: HPD1.1, J1.19 (HPD)
SCL: J1.15 (SCL), J2.15, U3.4, U3.7 (NC)
SDA: J1.16 (SDA), J2.16, U3.5, U3.6 (NC)
TMDS0+: J1.7 (D0+), J2.7, U2.1, U2.10 (NC)
TMDS0-: J1.9 (D0-), J2.9, U2.2, U2.9 (NC)
TMDS1+: J1.4 (D1+), J2.4, U1.4, U1.7 (NC)
TMDS1-: J1.6 (D1-), J2.6, U1.5, U1.6 (NC)
TMDS2+: J1.1 (D2+), J2.1, U1.1, U1.10 (NC)
TMDS2-: J1.3 (D2-), J2.3, U1.2, U1.9 (NC)
TMDSClk+: J1.10 (CK+), J2.10, U2.4, U2.7 (NC)
TMDSClk-: J1.12 (CK-), J2.12, U2.5, U2.6 (NC)
UTL: J1.14 (UTILITY), J2.14, U3.2, U3.9 (NC)

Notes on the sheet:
HDMI Pin 19
HDMI Pin 1

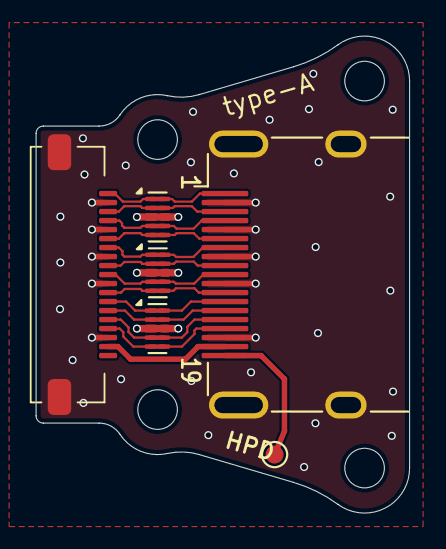
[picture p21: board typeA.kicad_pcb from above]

Board: 2 copper layers, 20.8 x 26.5 mm, 6 parts (0 on the bottom side), 15 nets.

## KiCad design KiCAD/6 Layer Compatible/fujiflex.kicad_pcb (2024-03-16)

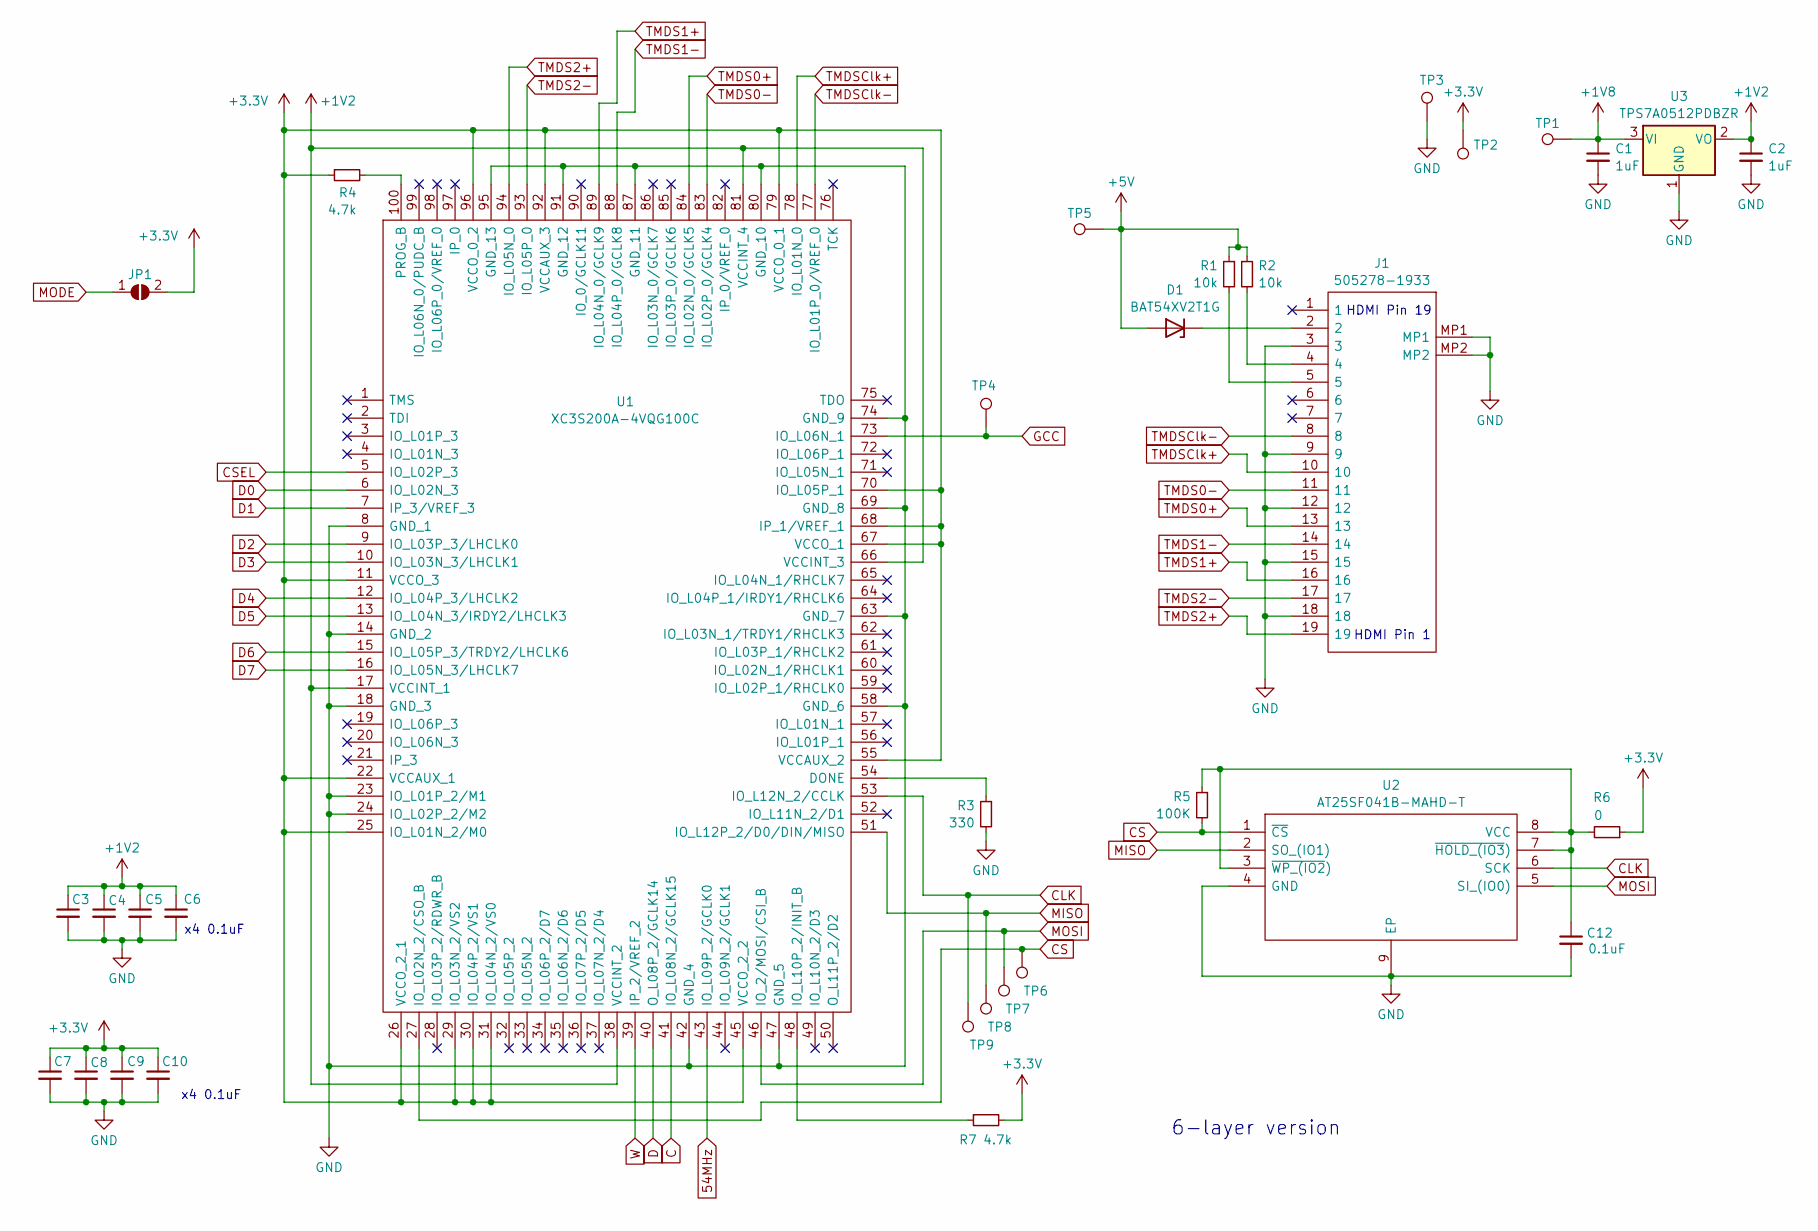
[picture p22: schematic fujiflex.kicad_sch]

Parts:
C1, C2: 1uF; C_0402_1005Metric
C3, C4, C5, C6, C7, C8, C9, C10, C12: 0.1uF; C_0402_1005Metric
D1: BAT54XV2T1G; D_SOD-523
J1: 505278-1933; 5052781933; Mouser Part Number 538-505278-1933
JP1: SolderJumper_2_Open; SolderJumper-2_P1.3mm_Open_RoundedPad1.0x1.5mm
R1, R2: 10k; R_0402_1005Metric
R3: 330; R_0402_1005Metric
R4, R7: 4.7k; R_0402_1005Metric
R5: 100K; R_0402_1005Metric
R6: 0; R_0402_1005Metric
TP1, TP2, TP3: TestPoint; TestPoint_Pad_D1.5mm
TP4, TP5: TestPoint; TestPoint_Pad_D1.0mm
TP6, TP7, TP8, TP9: TestPoint; TestPoint_Pad_D0.75mm
U1: XC3S200A-4VQG100C; QFP50P1600X1600X120-100N; Mouser Part Number 217-C3S200A-4VQG100C
U2: AT25SF041B-MAHD-T; SON50P300X200X60-9N-D; Mouser Part Number 988-AT25SF041BMAHDT
U3: TPS7A0512PDBZR; SOT-23

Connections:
54MHz: U1.43 (IO_L09P_2/GCLK0)
+1V2: C2.1, C3.1, C4.1, C5.1, C6.1, U1.17 (VCCINT_1), U1.38 (VCCINT_2), U1.66 (VCCINT_3), U1.81 (VCCINT_4), U3.2 (VO)
+1V8: C1.1, TP1.1, U3.3 (VI)
+3.3V: C7.1, C8.1, C9.1, C10.1, JP1.2 (B), R4.1, R6.1, R7.2, TP2.1, U1.11 (VCCO_3), U1.22 (VCCAUX_1), U1.25 (IO_L01N_2/M0), U1.26 (VCCO_2_1), U1.29 (IO_L03N_2/VS2), U1.30 (IO_L04P_2/VS1), U1.31 (IO_L04N_2/VS0), U1.45 (VCCO_2_2), U1.55 (VCCAUX_2), U1.67 (VCCO_1), U1.68 (IP_1/VREF_1), U1.70 (IO_L05P_1), U1.79 (VCCO_0_1), U1.92 (VCCAUX_3), U1.96 (VCCO_0_2)
+5V: D1.2 (A), R1.1, R2.1, TP5.1
C: U1.41 (IO_L08N_2/GCLK15)
CLK: TP9.1, U1.53 (IO_L12N_2/CCLK), U2.6 (SCK)
CS: R5.2, TP6.1, U1.27 (IO_L02N_2/CSO_B), U2.1 (~CS)
CSEL: U1.5 (IO_L02P_3)
D: U1.40 (O_L08P_2/GCLK14)
D0: U1.6 (IO_L02N_3)
D1: U1.7 (IP_3/VREF_3)
D2: U1.9 (IO_L03P_3/LHCLK0)
D3: U1.10 (IO_L03N_3/LHCLK1)
D4: U1.12 (IO_L04P_3/LHCLK2)
D5: U1.13 (IO_L04N_3/IRDY2/LHCLK3)
D6: U1.15 (IO_L05P_3/TRDY2/LHCLK6)
D7: U1.16 (IO_L05N_3/LHCLK7)
GCC: TP4.1, U1.73 (IO_L06N_1)
GND: C1.2, C2.2, C3.2, C4.2, C5.2, C6.2, C7.2, C8.2, C9.2, C10.2, C12.2, J1.3, J1.9, J1.12, J1.15, J1.18, J1.MP1, J1.MP2, R3.2, TP3.1, U1.8 (GND_1), U1.14 (GND_2), U1.18 (GND_3), U1.23 (IO_L01P_2/M1), U1.24 (IO_L02P_2/M2), U1.42 (GND_4), U1.47 (GND_5), U1.58 (GND_6), U1.63 (GND_7), U1.69 (GND_8), U1.74 (GND_9), U1.80 (GND_10), U1.87 (GND_11), U1.91 (GND_12), U1.95 (GND_13), U2.4 (GND), U2.9 (EP), U3.1 (GND)
MISO: TP8.1, U1.51 (IO_L12P_2/D0/DIN/MISO), U2.2 (SO_(IO1))
MODE: JP1.1 (A)
MOSI: TP7.1, U1.46 (IO_2/MOSI/CSI_B), U2.5 (SI_(IO0))
unnamed: D1.1 (K), J1.2
unnamed: J1.4, R2.2
unnamed: J1.5, R1.2
unnamed: R3.1, U1.54 (DONE)
unnamed: R7.1, U1.48 (IO_L10P_2/INIT_B)
unnamed: R4.2, U1.100 (PROG_B)
unnamed: C12.1, R5.1, R6.2, U2.3 (~WP_(IO2)), U2.7 (~HOLD_(IO3)), U2.8 (VCC)
TMDS0+: J1.13, U1.84 (IO_L02N_0/GCLK5)
TMDS0-: J1.11, U1.83 (IO_L02P_0/GCLK4)
TMDS1+: J1.16, U1.89 (IO_L04N_0/GCLK9)
TMDS1-: J1.14, U1.88 (IO_L04P_0/GCLK8)
TMDS2+: J1.19, U1.94 (IO_L05N_0)
TMDS2-: J1.17, U1.93 (IO_L05P_0)
TMDSClk+: J1.10, U1.78 (IO_L01N_0)
TMDSClk-: J1.8, U1.77 (IO_L01P_0/VREF_0)
W: U1.39 (IP_2/VREF_2)

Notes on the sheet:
6-layer version
HDMI Pin 1
x4 0.1uF
HDMI Pin 19

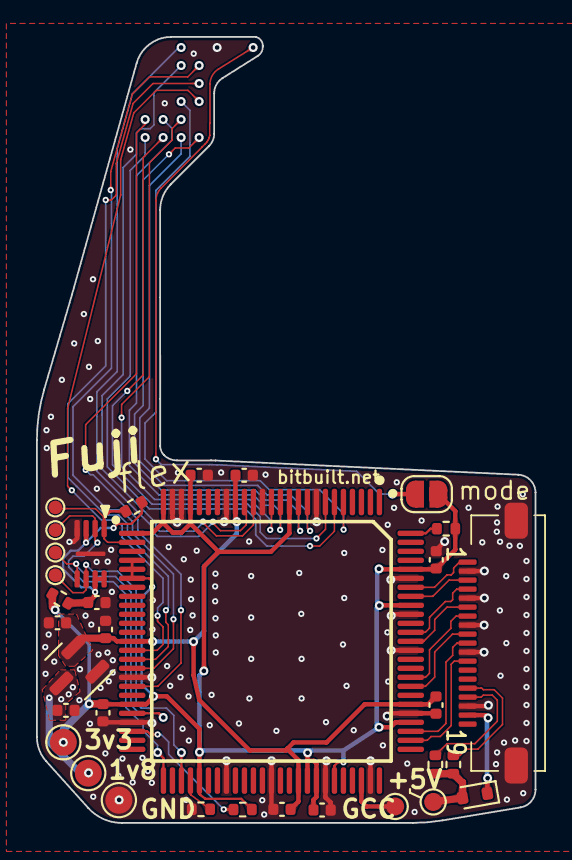
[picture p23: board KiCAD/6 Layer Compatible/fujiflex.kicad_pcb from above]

Board: 2 copper layers, 27.7 x 43.7 mm, 33 parts (0 on the bottom side), 25 nets.

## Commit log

2024-02-11 fix via
    [fujiflex.kicad_pcb]
2024-02-11 moar stitching vias
    [fujiflex.kicad_pcb]
2024-02-11 fix schematic
    [fujiflex.kicad_sch]
2024-02-12 add 6layer version
    [fujiflex.kicad_pcb, fujiflex.kicad_sch]
2024-02-13 minor routing fixes
    [fujiflex-B_Cu.gbr, fujiflex-B_Mask.gbr, fujiflex-B_Paste.gbr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]
2024-02-14 fix LDO blunder
    [fujiflex-B_Cu.gbr, fujiflex-B_Mask.gbr, fujiflex-B_Paste.gbr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]
2024-03-12 pcb fixes
    - tie IR button pin high
    - minor layout/routing tweaks
    - silkscreen edits
    - updated gerbers
    [fujiflex-B_Cu.gbr, fujiflex-B_Mask.gbr, fujiflex-B_Silkscreen.gbr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]
2024-03-14 Add some basic assembly, flashing, and installation docs
2024-03-16 minor layout updates
    -updated grounding and some via sizes
    -fixed IR button on 6L version
    -updated gerbers
    [fujiflex-B_Cu.gbr, fujiflex-B_Mask.gbr, fujiflex-B_Silkscreen.gbr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]
2024-04-11 add type-A adapter
    [typeA-B_Cu.gbr, typeA-B_Mask.gbr, typeA-B_Silkscreen.gbr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]
2024-04-11 add dimensions
    [typeA.kicad_pcb]
2024-04-11 add typeC adapter
    [typeC-B_Cu.gbr, typeC-B_Mask.gbr, typeC-B_Silkscreen.gbr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]
2024-04-11 working on JLC PCBA files
    [BOM-fujiflex.csv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]
2025-02-02 update to 9
    [fujiflex.kicad_pcb, fujiflex.kicad_sch]
2025-02-02 embed fonts + 3d, update gerbers
    [fujiflex-B_Cu.gbr, fujiflex-B_Mask.gbr, fujiflex-B_Silkscreen.gbr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]
2025-02-02 embed 3d
    [fujiflex.kicad_pcb]
2025-02-27 pcbway prod files
    [Sample_BOM_PCBWay.xlsx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]
2025-03-06 progress on factory test jig
    [main_jig.kicad_pcb, main_jig.kicad_sch]
